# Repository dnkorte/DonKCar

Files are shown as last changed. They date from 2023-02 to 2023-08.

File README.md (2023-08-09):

This project holds files related to the DonKCar project, which is an
implementation of autonomous RC-sized racer.  The project includes
OpenSCAD code to generate 3d-printable chassis that fit a variety
of purchasable RC car platforms; the chassis is user-configurable
and currently includes built-in options to generate models including a 
variety of hardware configurations including Raspberry Pi
and/or Jetson Nano for DonkeyCar implementations, and OpenMV-based
solutions using ESP32-S2 on an Adafruit Metro board as a main controller.  

The OpenSCAD modules in this project are dependent on the use of the 
lib_robo files which are available in [a separate repository here](https://github.com/dnkorte/lib_robo).
The "include" links in the OpenSCAD modules must be updated
to point to the lib_robo library files, wherever you have stored them in
your filesystem

All plates may be automatically "split" so that they can be printed
on standard 180x180mm or larger 3d-printers.  The designs are currently 
configured for the following RC chassis:

*[1/10 Tamiya TT02B Neo Scorcher (2-post)](https://smile.amazon.com/gp/product/B00DSVF3BY)

*[1/10 Tamiya TT02 Toyota GR 86  (4-post)](https://www.amazon.com/TAMIYA-10-Toyota-TT-02-TAM58694/dp/B09KRR5GKS)

*[Hosim 1/12 Monster Truck](https://www.amazon.com/Hosim-9155-Speed-Monster-Trucks/dp/B07SRTHB3L?th=1) 

*[Holyton 1:10 Large High Speed Remote Control Car](https://www.amazon.com/dp/B08B1F3494)

*[Electric Infinitive EP RTR Off Road Truck](https://www.nitrorcx.com/51c803-truck-ttyellowcarbon.html)

Note that these are all readily available chassis in early 2023

<h3 align="center">
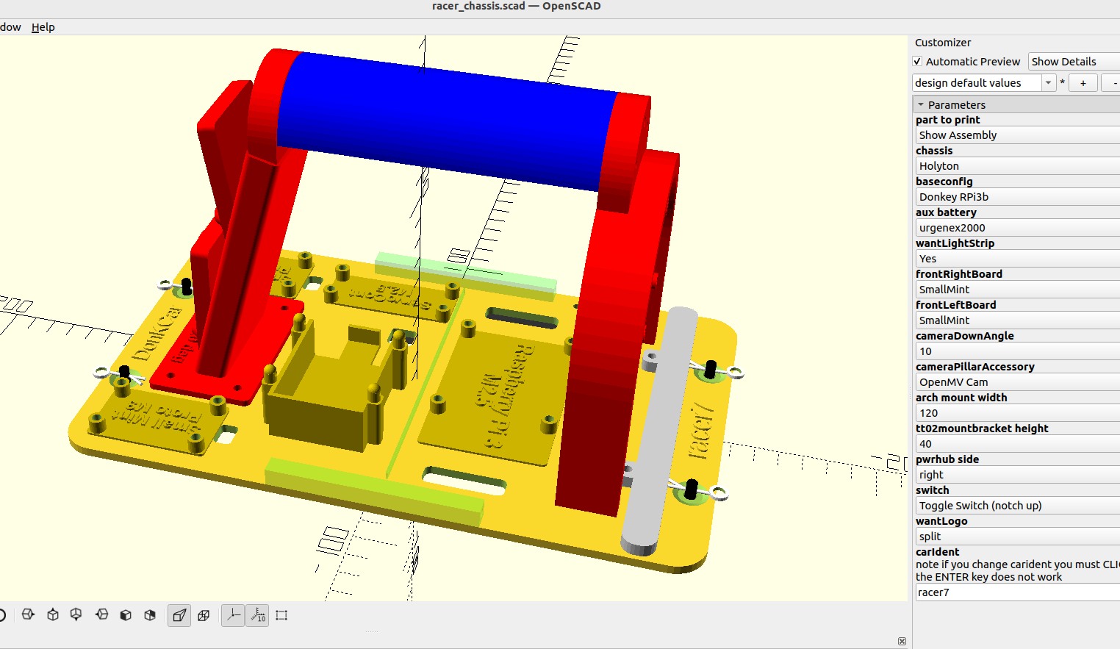
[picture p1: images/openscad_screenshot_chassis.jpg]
sample openscad screen
	<br>
</h3>

If using a standard DonkeyCar software package on either a Raspberry Pi or Jetson Nano, none of the Arduino code packages are needed, and the OpenSCAD models are very stable and complete for those configurations.

## ESP32-S2 + OpenMV Configuration

This project has includes an (optional) as-yet still under software/hardware development option  that uses an OpenMV camera for the vision and lane-tracking portions and uses an ESP32-S2 (Adafruit Metro ESP32-S2 board) as a vehicle / platform main controller.  At the current time, the manual driving and core functions are very complete and functional -- allowing manual driving of the vehicle using a remote controller (clips to driver's belt), and allowing for setup/configuration using a self-hosted web menu system that works with a phone or laptop (straight-up web interface no software installation needed on the phone or laptop).  The onboard ESP32-S2 software incorporates a 240x240 TFT display for detailed user feedback, and a 24 element NeoPixel strip that provides runtime feedback for users "at a distance" and also talks bi-directionally to the nunchuk controller.  

The belt-mounted remote controller uses an Adafruit Reverse Feather ESP32-S2 with a built-on TFT display connected to a Wii Nunchuk controller that provides driving commands. The remote communicates with the racer using ESP-NOW protocol which means that all control is totally independent of local networks, and is bi-directional and responsive.

All of the above works at the current time, with the software as included here.  

The autonomous driving functions using the OpenMV camera are still under development, but are modelled on the OpenMV line following protocols, modified to communicate to the main controller over an i2c connection.  The racer main controller handles the actual throttle and steering servo commands, accepting path commands provided by the OpenMV software.  

**Note that the ESP32-S2 / OpenMV configuration is currently very much still under development so use or reference at your own risk.**

<table><tr>
	<td>
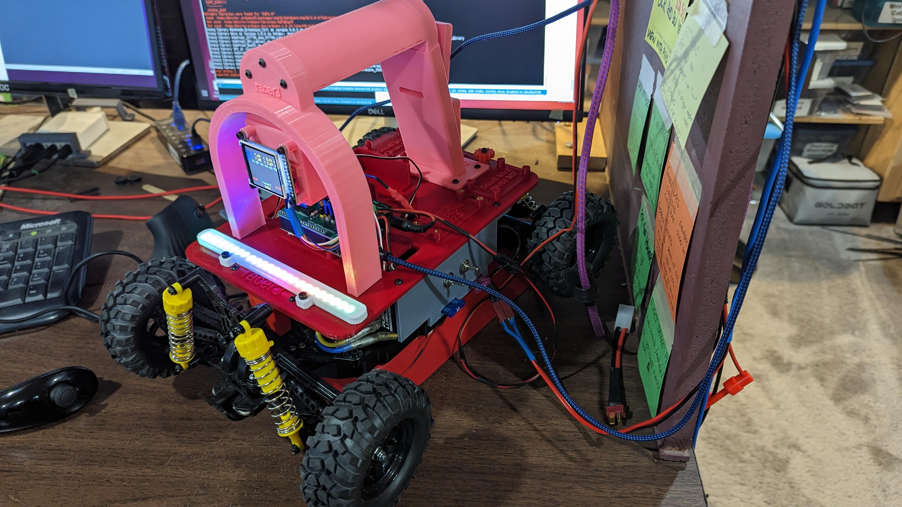
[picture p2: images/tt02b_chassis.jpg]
Tamiya TT02b 2-post chassis printed in 1 piece
		
	</td>
	<td>
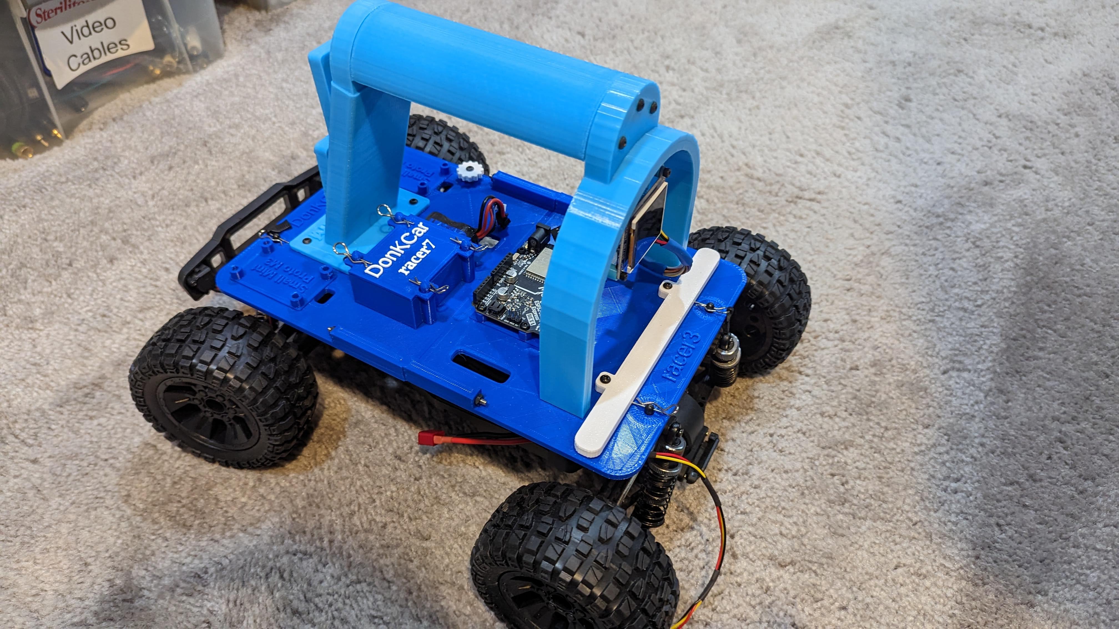
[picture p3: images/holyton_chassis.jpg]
Holyton RTR chassis printed in 2 pieces, joined
		
	</td>
	<td>
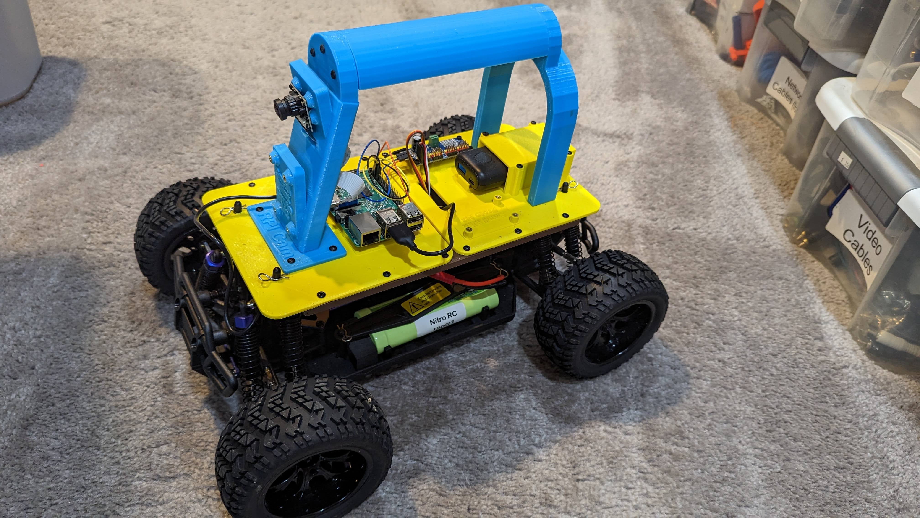
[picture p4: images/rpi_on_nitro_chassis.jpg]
Raspberry Pi on Nitro RCX chassis (older scad design)
		
	</td>
</tr></table>

## Remote Controller Using Nunchuk
The user controls the racer / robot using a Wii Nunchuk control unit that plugs into a belt-clipped or lanyard-mounted control box that includes a 240 x 135 TFT.  An [Adafruit Reverse TFT Feather](https://www.adafruit.com/product/5345) uses ESP-NOW protocol to communicate bi-directionally with the racer / robot.  It sends joystick and button-press commands to the racer, and receives messages back from racer for display on the TFT.  It is a very quick and responsive protocol with good range (at least 100 feet in my yard, but not tested any farther). The simple messaging protocol could be easily used to control any robot / racer configuration.  The control box is powered by a small LiPo battery and may be worn using a belt-clip or a [neck lanyard](https://www.amazon.com/Bestom-Breakaway-Lanyards-Lanyards-no-Twist/dp/B09LQJJHFQ) (of the type typically used for ID badges).  

Some photos of the controller box are shown below, or a more complete [photo album is available here](https://photos.app.goo.gl/xJtTXaHJivE7bsBp9), and [short video of unit in operation is linked here](https://photos.app.goo.gl/UN85hcr63vpKxPkb9).  Additionally, a document describing the communication protocol is available [here](https://github.com/dnkorte/DonKCar/blob/main/Protocol_for_Nunchuk_Controller_for_Racer_Robot.pdf)

<table><tr>
	<td>
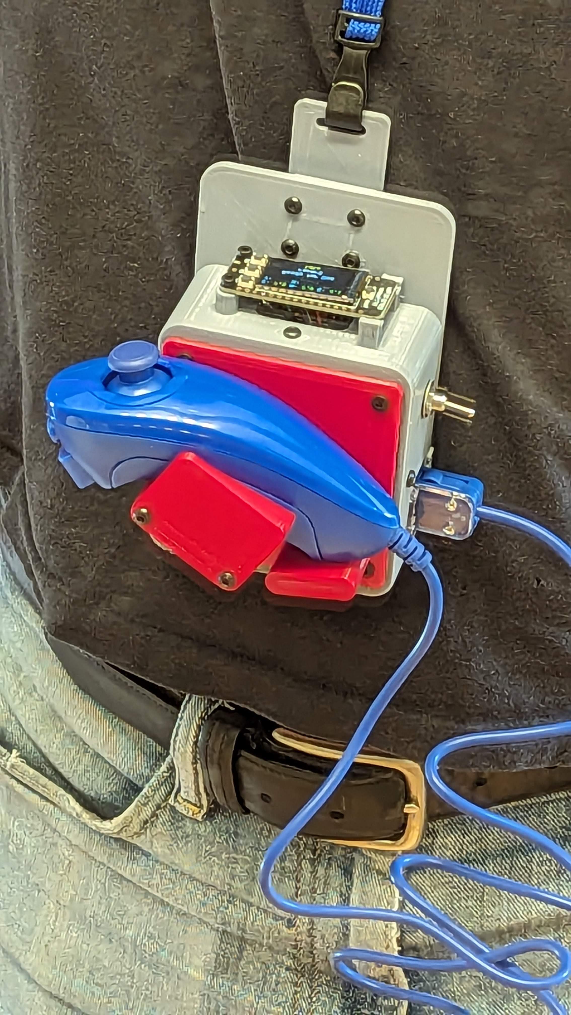
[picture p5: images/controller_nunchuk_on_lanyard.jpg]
Controller on Lanyard
		
	</td>
	<td>
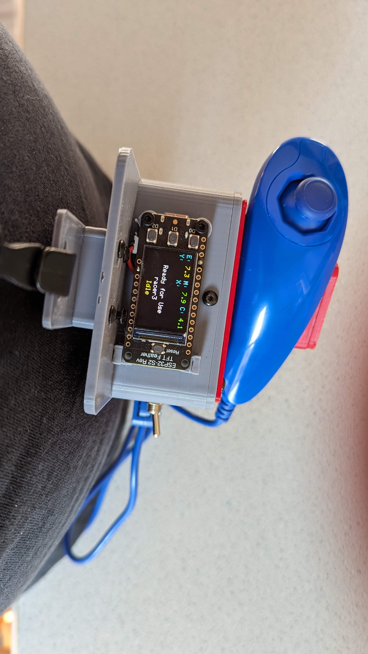
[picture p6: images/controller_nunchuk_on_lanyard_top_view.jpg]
Controller on Lanyard
		
	</td>
	<td>
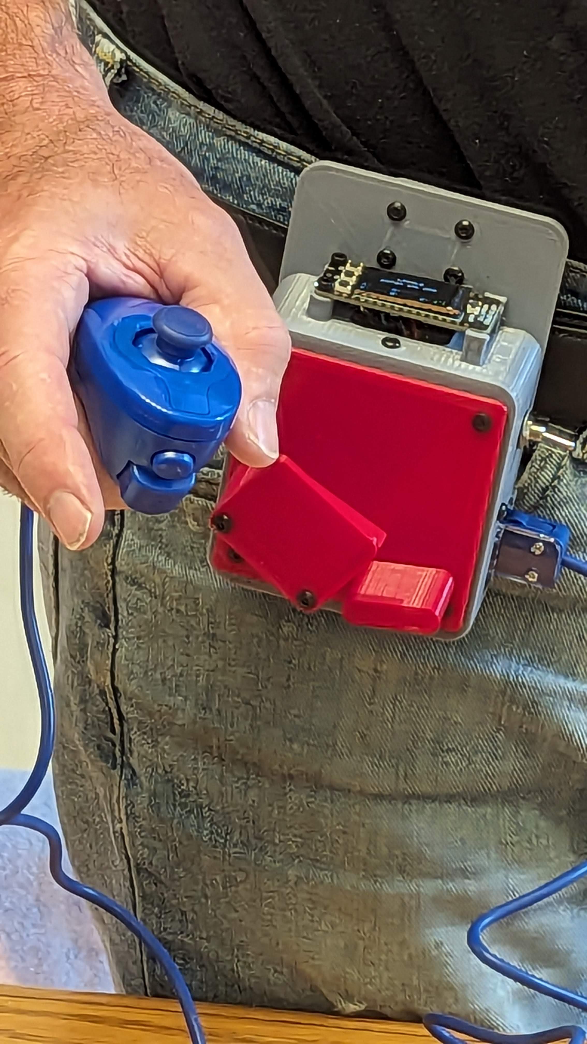
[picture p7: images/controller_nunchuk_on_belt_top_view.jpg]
Controller on belt-clip
		
	</td>
</tr><tr>
	<td colspan=3>
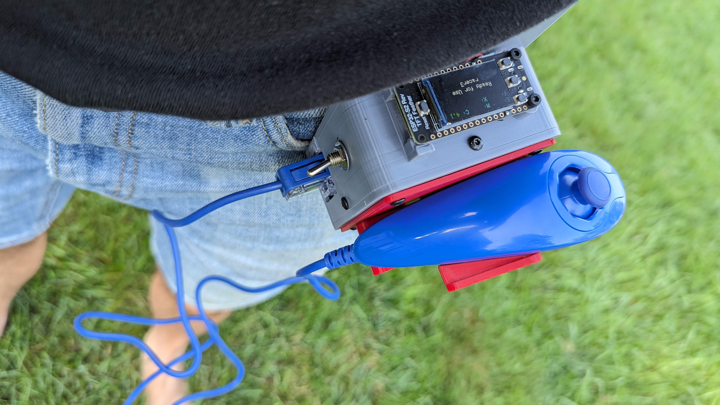
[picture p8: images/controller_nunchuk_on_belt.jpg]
Controller on belt-clip
		
	</td>

</tr></table>

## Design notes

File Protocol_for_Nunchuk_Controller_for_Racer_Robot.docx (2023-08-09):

# Protocol for Nunchuk Controller (racer/robot)

Messages between Controller and Robot are sent over ESP-NOW protocol, using short binary structures defined in the Arduino code as indicated in the following sections. The MAC address of the responding robot or racer is hard encoded into the “communic.cpp” module of the software. Note that in the current version of the software, there are 3 values indicated, though only the first one (index 0) is actually used at this time.

### Colorcodes

For those incoming messages that receive colorcodes, the code is a single char value, as follows:

- ‘G’ Green
- ‘Y’ Yellow
- ‘O’ Orange
- ‘R’ Red
- ‘W’ White
- ‘X’ Black
- ‘B’ Blue
- ‘C’ Cyan
- ‘P’ Purple
- ‘Z’ Medium Gray
- ‘H’ (header color; cyan)

### Controller to Robot Messages

typedef struct {

char msgtype; // 'C', 'Z', 'X', 'Y', 'V', 'H', '0', '1', '2'

int intdata; // note this is a 2-byte (16 bit) integer

} MessageCtoR; // this type (structure) holds a message that goes from

Controller to Robot

All messages are 3 bytes long, with the 1st byte indicating the message type, and the following 2 bytes (Arduino 2 byte integer) holding the value associated with the message. All reported intdata are LSB first.

Message type ‘C’ :

This indicates the status of the Nunchuk ‘C’ button (the “upper” one on the Nunchuk device). The intdata value is integer 1 when button PRESS is detected, and 0 when button RELEASE is detected.

Button 2

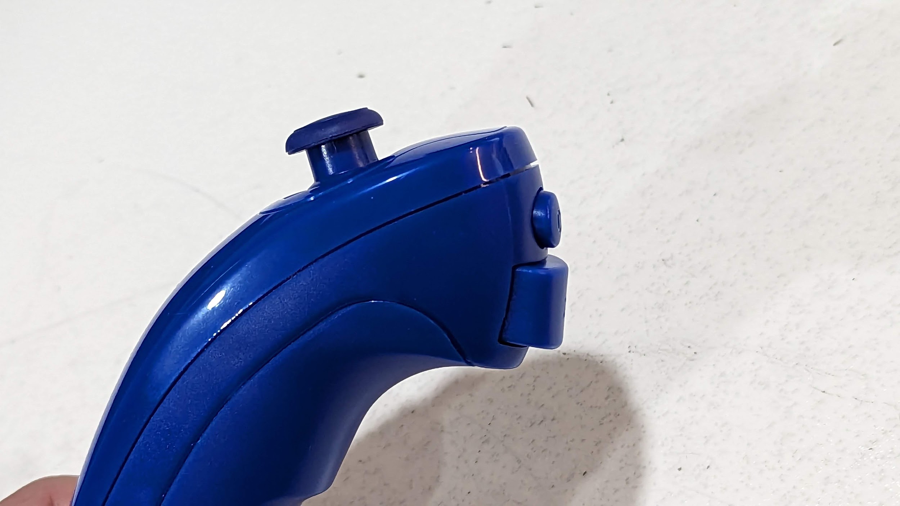
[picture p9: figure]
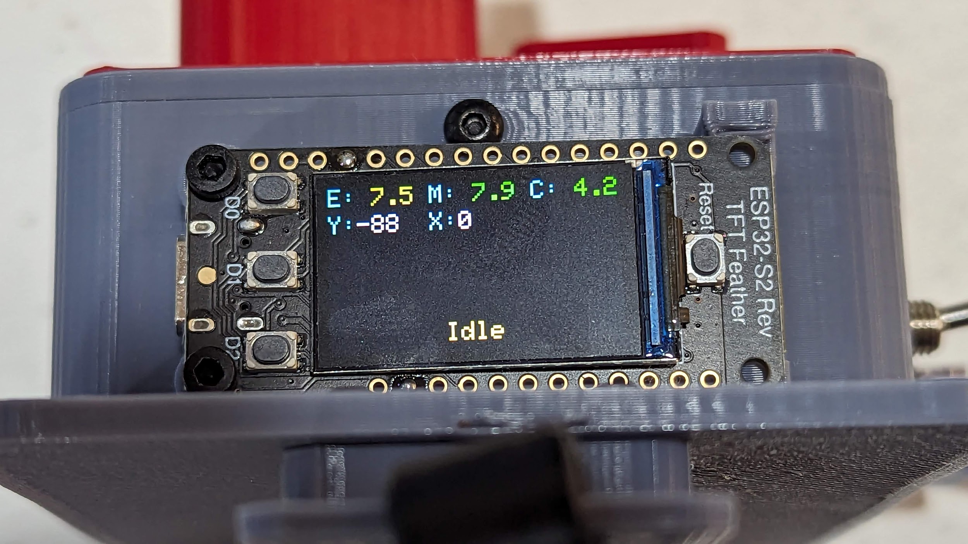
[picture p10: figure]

C button

Z button

Btn 0

Btn 1

Btn 2

Message type ‘Z’ :

This indicates the status of the Nunchuk ‘Z’ button (the “lower” one on the Nunchuk device). The intdata value is integer 1 when button PRESS is detected, and 0 when button RELEASE is detected.

Message type ‘0’ :

This indicates the status of the Feather ‘0’ button. The intdata value is integer 1 when button PRESS is detected, and 0 when button RELEASE is detected.

Message type ‘1’ :

This indicates the status of the Feather ‘1’ button. The intdata value is integer 1 when button PRESS is detected, and 0 when button RELEASE is detected.

Message type ‘2’ :

This indicates the status of the Feather ‘2’ button. The intdata value is integer 1 when button PRESS is detected, and 0 when button RELEASE is detected.

Message type ‘X’:

This message sends the X value of the joystick (left and right). The value in intdata is scaled such that FULL LEFT reports -255, and FULL RIGHT reports +255. The value is reported whenever it changes by 2 or more, and has a small deadband at center to reduce jitter.

Message type ‘Y’:

This message sends the Y value of the joystick (forward and back). The value in intdata is scaled such that FULL BACK reports -255, and FULL FORWARD reports +255. The value is reported whenever it changes by 2 or more, and has a small deadband at center to reduce jitter.

Message type ‘H’:

This message sends a “heartbeat’ indication to the racer / robot for the purpose of indicating that it is alive and connected. The message is sent once every 1000 mS. The intvalue is irrelevant in this message.

Message type ‘V’:

This message is currently not used, but is intended to send the binary value representing the battery voltage of the LiPo in the control box.

### Robot to Controller Messages - Battery Status

typedef struct {

uint8_t messagetype;

char colorcode;

float battvolts;

float cellvolts;

} MessageRtoC_batt; // this type (structure) holds a message that goes from

Robot to Controller

This message is sent from the racer / robot to the controller and indicates the robot’s battery voltage (and corresponding cell voltage for multi-cell batteries) for purposes of display.

- messagetype: 0 (MSG_VOLTS_E) indicates voltage of the PRIMARY battery (the one that feeds the processor and displays), 1 (MSG_VOLTS_M_ indicates the voltage of the MOTOR battery
- colorcode: character indicating color that should be used to display the passed voltages, per the table above. Generally the colorcode reflects the level of charge (ie, G/reen, Y/ellow, O/range, R/ed)
- battvolts: floating point value representing the battery voltage (ie 8.2). This is presented LSB first
- Cellvolts: floating point value representing the cell voltage (ie 3.7) for multicell batteries. Will be the same as battvolts for single cell batteries. This is presented LSB first

### Robot to Controller Messages - Status Text

typedef struct {

uint8_t messagetype;

char colorcode;

char text[22];

} MessageRtoC_text; // this type (structure) holds a message that goes from

Robot to Controller

This message type is sent from racer / robot to the controller and contains a text string for display on the controller’s TFT screen. There are 3 lines available for status messages. All messages are centered on their display line and are automatically cleared (erased) after 30 seconds.

- messagetype: 2 (MSG_STAT1) for first status line, 3 (MSG_STAT2) for second status line, 4 (MSG_STAT3) for third status line
- colorcode: character indicating color that should be used to display the passed text, per the table above.
- Text: the text to display as an Arduino character array; messages are null (\0) terminated

### Robot to Controller Messages - ModeMenu Text

typedef struct {

uint8_t messagetype;

char colorcode;

char text[22];

} MessageRtoC_text; // this type (structure) holds a message that goes from

Robot to Controller

This message type is sent from racer / robot to the controller and contains a text string for display on the bottom line of the controller’s TFT screen. The bottom line is typically used to indicate the “Mode” that the robot / racer is operating in, or about to operate in if is reflecting a menu possibility.

- messagetype: 5 (MSG_MENUITEM)
- colorcode: character indicating color that should be used to display the passed text, per the table above.
- Text: the text to display as an Arduino character array; messages are null (\0) terminated

### Robot to Controller Messages - Simple Message

typedef struct {

uint8_t messagetype;

char colorcode;

} MessageRtoC_simple; // this type (structure) holds a message that goes from

Robot to Controller

This message type is sent from racer / robot to the controller for simple commands or messages, such as “clear display” or “beep”. Currently neither of these messages are actually implemented for the controller

### Joystick Values Display

The second line of the controller’s TFT is used to display the joystick values, X and Y. This display is internally driven and does not require any messages from the robot / racer.

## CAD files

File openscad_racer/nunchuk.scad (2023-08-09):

/*
 * Module: nunchuk.scad
 * this main module generates a box to hold components of a belt-clip portable
 * box into which a user can plug a Wii Nunchuk controller which can then be
 * used to control an RC Car or robot. 
 *
 * Project: DonKCar
 * Author(s): Don Korte
 * github: https://github.com/dnkorte/DonKCar.git
 * 
 *  
 * MIT License
 * 
 * Copyright (c) 2023 Don Korte
 * 
 * Permission is hereby granted, free of charge, to any person obtaining a copy
 * of this software and associated documentation files (the "Software"), to deal
 * in the Software without restriction, including without limitation the rights
 * to use, copy, modify, merge, publish, distribute, sublicense, and/or sell
 * copies of the Software, and to permit persons to whom the Software is
 * furnished to do so, subject to the following conditions:
 * 
 * The above copyright notice and this permission notice shall be included in all
 * copies or substantial portions of the Software.
 * 
 * THE SOFTWARE IS PROVIDED "AS IS", WITHOUT WARRANTY OF ANY KIND, EXPRESS OR
 * IMPLIED, INCLUDING BUT NOT LIMITED TO THE WARRANTIES OF MERCHANTABILITY,
 * FITNESS FOR A PARTICULAR PURPOSE AND NONINFRINGEMENT. IN NO EVENT SHALL THE
 * AUTHORS OR COPYRIGHT HOLDERS BE LIABLE FOR ANY CLAIM, DAMAGES OR OTHER
 * LIABILITY, WHETHER IN AN ACTION OF CONTRACT, TORT OR OTHERWISE, ARISING FROM,
 * OUT OF OR IN CONNECTION WITH THE SOFTWARE OR THE USE OR OTHER DEALINGS IN THE
 * SOFTWARE.
 */

part_to_print="box with 1200 mAH";  // [ "box with 1200 mAH", "box with 500 mAH", "lid without hanger", "lid for Nunchuk cradle", "lid for Nunchuk hanger", "Nunchuk Cradle plate", "Cap for Nunchuk Cradle", "Nunchuk Hanger plate", "beltclip", "lanyard clip", "battbox_lid 500", "battbox_lid 1200", "test" ]

draw_part();

module draw_part() {
    $fn = 36;
    

    if (part_to_print == "beltclip") {
        part_beltclip();
    } else if (part_to_print == "lanyard clip") {
        part_lanyard_clip();
    } else if (part_to_print == "battbox_lid 500") {
        component_battbox_lipo_500_flat_lid();
    } else if (part_to_print == "battbox_lid 1200") {
        component_battbox_lipo_1200_flat_lid();
    } else if (part_to_print == "box with 1200 mAH") {
        box_feather("1200");
    } else if (part_to_print == "box with 500 mAH") {
        box_feather("500");
    } else if (part_to_print == "lid without hanger") {
        lid_feather("N");
    } else if (part_to_print == "lid for Nunchuk hanger") {
        lid_feather("H");
    } else if (part_to_print == "lid for Nunchuk cradle") {
        lid_feather("C");
    } else if (part_to_print == "Nunchuk Cradle plate") {
        nunchuk_cradle_plate();
    } else if (part_to_print == "Cap for Nunchuk Cradle") {
        nunchuk_cradle_cap();
    } else if (part_to_print == "Nunchuk Hanger plate") {
        nunchuk_hanger_plate();
    } else if (part_to_print == "test") {
        translate([ 0, 0, 2 ]) nunchuk_hanger();
        roundedbox(50, 50, 3, 2);
    }
}

box_length = 80;
box_width = 120;
box_height = 37;
box_corner_radius = 8;

feather_box_length = 80;
feather_box_width = 85;
feather_plate_width = 120;
feather_box_height = 35;
hanger_mount_sep = 42;
cradle_mount_sep = 62;

plate_thick = 3;
wall_thick = 5;
wall_height = 16;
corner_radius = 8;

plate_x = 80;
plate_y = 120;

beltclip_hole_sep_x = 20;
beltclip_hole_sep_y = 15;

mountplate_thick = 2;

/*
 ************************************************************************************************
 * this includes all of the needed library modules
 ************************************************************************************************
 */
include <../../lib_robo/config_core.scad>;
include <../../lib_robo/config_box.scad>
include <../../lib_robo/components_core.scad>;
include <../../lib_robo/components_boards.scad>;
include <../../lib_robo/components_switches_and_lights.scad>;
include <../../lib_robo/components_power_batteries.scad>;
include <../../lib_robo/components_power_boards.scad>;
include <../../lib_robo/components_power_fuses_connectors.scad>;
//include <../../lib_robo/components_camera_rollbar.scad>;
include <../../lib_robo/simple_box_and_lid.scad>
include <../../lib_robo/components_robo_misc.scad>; 

/*
 * *****************************************************************
 * mainl box-building code for drawing parts
 * most standard components are already handled here, by means
 * of configuration parameters, however custom parts may be
 * added by adding appropriate code to these modules
 * *****************************************************************
 */

module box_feather(batteryFlavor = "1200") {
    nunchuk_window_wide = 27;   // was 27
    nunchuk_window_tall = 20;   // should raise it 5 above box bottom (was 22)

    usb_window_wide = 14;
    usb_window_tall = 8;
    usb_window_height = 15;

    difference() {
        union() {
            // the basic hollow box
            difference() {
                roundedbox(feather_box_length, feather_box_width, box_corner_radius, box_height);
                translate([0, 0, body_bottom_thickness])  
                    roundedbox((feather_box_length - 2*body_wall_thickness), 
                           (feather_box_width - 2*body_wall_thickness), 
                           box_corner_inner_radius, 
                           (box_height - body_wall_thickness+1));
            }

            /*
             ************************************************************************
             * here enter all the parts that are added to the box
             ************************************************************************
             */
            translate([  0, -(feather_plate_width-feather_box_width)/2, 0 ]) roundedbox( box_length, feather_plate_width, box_corner_radius, plate_thick);

            if (batteryFlavor == "1200") {
                translate([ -10, 5, plate_thick ]) rotate([ 0, 0, 0 ]) component_battbox_lipo_1200_flat("adds");
            } else {
                translate([ -10, 0, plate_thick ]) rotate([ 0, 0, 0 ]) component_battbox_lipo_500_flat("adds");
            }

            translate([ (plate_x/2)-13, 20, plate_thick-1 ]) rotate([ 0, 0, 90 ]) part_nunchuk();
            
            translate([ (plate_x/2)-1, 20, 1 ]) rotate([ 90, 90, 90 ]) rotate([ 0, 0, 90 ]) 
                linear_extrude(2) text("Notch", size=6,  halign="center", font = "Liberation Sans:style=Bold");  

            translate([ 0, -(feather_box_length/2)-1.5, plate_thick+15 ]) rotate([ 90, 180, 0 ]) component_reverse_feather(mode="adds", mount_height=7);

        }

        // create mounting holes along y side (by removal...)
        translate([-(box_length/2)-0.1, 0, (box_height - mount_center_offset_from_boxtop)]) rotate([0,90,0])  
              cylinder(h=box_length+0.2, r=screwhole_radius_M30_passthru);
      
        // create mounting holes along x side
        translate([0, -(box_width/2)-0.1, (box_height - mount_center_offset_from_boxtop)]) rotate([0,90,90])  
              cylinder(h=box_width+0.2, r=screwhole_radius_M30_passthru);

        /*
         ************************************************************************
         * here enter all the parts that are removed from the box
         ************************************************************************
         */
        translate([ 0, -63, -0.1 ]) component_beltclip_mount();


        if (batteryFlavor == "1200") {
            translate([ -10, 5, plate_thick ]) rotate([ 0, 0, 0 ]) component_battbox_lipo_1200_flat("holes");
        } else {
            translate([ -10, 0, plate_thick ]) rotate([ 0, 0, 0 ]) component_battbox_lipo_500_flat("holes");
        }

        translate([ (box_length/2)+0.1, -20, box_height/2 ]) rotate([ 90, 180, 0 ]) rotate([ 0, 90, 180 ]) component_mini_toggle_switch("holes");

        translate([ 0, -(feather_box_length/2)+0, plate_thick+15 ]) rotate([ 90, 0, 0 ]) roundedbox( 30, 16, 3, 6);
        translate([ 0, -(feather_box_length/2)-1.5, plate_thick+15 ]) rotate([ 90, 180, 0 ]) component_reverse_feather(mode="holes", mount_height=7);

        // access hole for nunchuk connector
        translate([ (plate_x/2)+0.1, 20, 4.2 + plate_thick + (nunchuk_window_tall/2) ]) rotate([ 0, -90, 0 ]) 
            roundedbox( nunchuk_window_tall, nunchuk_window_wide, 2, body_wall_thickness+0.2); 

    }
}


module lid_feather(want_plate = "C") {   
    difference() {

        union() {
            roundedbox(feather_box_length, feather_box_width, box_corner_radius, lid_thickness);
            translate([0, 0, lid_thickness]) lip(feather_box_length, feather_box_width);
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

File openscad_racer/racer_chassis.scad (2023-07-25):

/*
 * Module: racer_chassis.scad
 * this main module generates 3d-printable mounting plates and 
 * components for a variety of purchasable RC Car chassis platforms. 
 * these chassis hold cameras and electronics to support Autonomous Racer
 * projects.  Use of the OpenSCAD "customizer" allows the user to simply
 * select appropriate parts to build various configurations of racer --
 * including built-in options compatible with DonkeyCar Raspberry Pi 3b,
 * DonkeyCar Jetson Nano, and a custom DonKCar platform based on the OpenMV
 * camera running in conjunction with ESP32 based communication and main control.
 *
 * Project: DonKCar
 * Author(s): Don Korte
 * github: https://github.com/dnkorte/DonKCar.git
 * 
 *  
 * MIT License
 * 
 * Copyright (c) 2023 Don Korte
 * 
 * Permission is hereby granted, free of charge, to any person obtaining a copy
 * of this software and associated documentation files (the "Software"), to deal
 * in the Software without restriction, including without limitation the rights
 * to use, copy, modify, merge, publish, distribute, sublicense, and/or sell
 * copies of the Software, and to permit persons to whom the Software is
 * furnished to do so, subject to the following conditions:
 * 
 * The above copyright notice and this permission notice shall be included in all
 * copies or substantial portions of the Software.
 * 
 * THE SOFTWARE IS PROVIDED "AS IS", WITHOUT WARRANTY OF ANY KIND, EXPRESS OR
 * IMPLIED, INCLUDING BUT NOT LIMITED TO THE WARRANTIES OF MERCHANTABILITY,
 * FITNESS FOR A PARTICULAR PURPOSE AND NONINFRINGEMENT. IN NO EVENT SHALL THE
 * AUTHORS OR COPYRIGHT HOLDERS BE LIABLE FOR ANY CLAIM, DAMAGES OR OTHER
 * LIABILITY, WHETHER IN AN ACTION OF CONTRACT, TORT OR OTHERWISE, ARISING FROM,
 * OUT OF OR IN CONNECTION WITH THE SOFTWARE OR THE USE OR OTHER DEALINGS IN THE
 * SOFTWARE.
 */

part_to_print="Show Assembly";  // [ "Top Plate", "Top Plate (front half)", "Top Plate (back half)", "Show Assembly", "RPi Cam Pillar (no handle)", "RPi Cam Pillar (with handle)", "OpenMV Cam Pillar (no handle)", "OpenMV Cam Pillar (with handle)", "Back Arch", "Back Arch w/TFT", "NeoPixel Bezel Indoors", "NeoPixel Bezel Outdoors", "Handle", "Mount Pillar (car-to-plate; TT02 single-post design)", "Power Hub", "Fuse Holder Lid", "Battery Box Lid", "Thumbnut 12", "Thumbnut 15", "Thumbnut 18", "Thumbnut 18 tall", "Thumbnut 18 super",  "test" ]

chassis = 0; // [0:TT02B-2, 1:TT02B-2 Extended, 2:TT02-4, 3:Holyton, 4:Hosim, 5:Exceed, 6:Custom ]

baseconfig = "metro"; // ["metro", "Donkey RPi3b", "Donkey Jetson Nano"]
aux_battery = "none"; // ["none", "anker6700", "urgenex2000", "NiMH 7.2v 2200 mAH" ]

wantLightStrip = "Yes"; // [ "Yes", "No" ]

frontRightBoard = "None"; // ["SmallMint", "None"]
frontLeftBoard = "None"; // ["SmallMint",  "None"]

cameraDownAngle = 10;	// [ 5, 10, 12, 15, 17, 20, 25, 30, 35 ]
cameraPillarAccessory = "OpenMV Cam"; // [ "OpenMV Cam", "RPi Cam", "SmallMint Proto", "None"]
arch_mount_width = 120; // [ 88, 120, 135 ]

tt02mountbracket_height = 40; // [ 35, 40, 45, 50 ]

pwrhub_side = "right"; // ["right", "left"]
switch = "Toggle Switch (notch up)"; // [ "Toggle Switch (notch up)", "Toggle Switch (notch down)", "Boat Rocker Switch"]

wantPCA9685 = "only Pi/Nano"; // ["only Pi/Nano", "all configurations"]

wantLogo = "split"; // [ "arch", "split", "none" ]
// note if you change carident you must CLICK out of box; the ENTER key does not work
carIdent = "racer3";


/*
 *********************************************************************
 * define a dummy function here, to stop the configurator "fields phase"
 *********************************************************************
 */

module dummy() {
	// this doesn't do anything useful
}

/*
 *********************************************************************
 * define other parameters that don't want configurator fields
 *********************************************************************
 */

// note for all dimensions on plate, the center of the body mount pins is the origin (0,0) point
// and "forward" is (+), "backward" is (-);  left is (-), right is (+)

// note indices are:  0/TT02-2,      1/TT02-2 ext, 2/TT02-4,   3/Holyton,   4/Hosim,   5/Exceed,  6/Custom

pillars_fb_sep =      [ 224,         224,         260,         253,         194,       261,			253 ];
// left/right separation may be different at front end than at back, so here show [front sep, back sep]
pillars_lr_sep =      [ [60,60],     [60,60],     [65,65],     [73,83],     [54,54],    [80,80],	    [73,83] ];
pillars_dia = 		  [ 3.5,         3.5,		  7.2,         5.5,         5.5,        7.2, 		7.2 ];
pillars_max_depth =	  [ 4,           4,           4,           3,           1.8,          4,          4 ];

added_fronts =        [ 10,          10,          10,          10,          65,         10,			10 ];
added_backs =         [ 10,          30,          10,          10,          10,         10, 		10 ];
plate_widths =        [ 170,         170,         170,         170,         170,        170, 		170 ];

// ligthstrip locations (POSITIVE but as distance behind origin), 2nd parameter is "n" or "r"
// "n" indicates normal mounting-tab-forward orientation, "r" indicates mounting-tab-backward orientation
lightStrip_locs =     [ [101,"r"],    [130,"n"],   [108,"r"],  [110,"n"],   [78,"r"],   [112,"n"], 	[110,"n"] ];

// for these features, params are x, y
metro_locs =          [ [0,-42],     [0,-50],     [0,-40],     [0,-38],     [0,-22],    [0,-44],    [0,-38] ];
rpi3b_locs =          [ [0,-42],     [0,-50],     [0,-40],     [0,-39],     [0,-22],    [0,-44],    [0,-38] ];
jetson_locs =         [ [0,-52],     [0,-55],     [0,-46],     [0,-47],     [0,-28],    [0,-48],    [0,-47] ];
frontL_locs = 		  [ [-58, 92],   [-58, 92],   [-60, 100],  [-60, 100],  [-60, 124],  [-62, 100], [-60, 101] ];
frontR_locs =         [ [58, 92],    [58, 92],    [60, 100],   [60, 100],   [60, 124],   [62, 100],  [60, 101] ];

// for servo locs, params are x, y, z-rotation
servo_locs =          [ [58, 23],    [58, 21],    [58, 31],    [58, 28],    [58, 50],   [58, 32],   [58, 28] ];

// for aux batteries, params are x, y, z-rotation
auxb_ank67_info =     [ [35,47,180], [35,47,180], [35,52,180], [35,54,180], [35,76,180], [35,60,180],  [35,54,180]  ];
auxb_urge_info =      [ [-55,2,0],   [-55,2,0],   [-55,12,0],  [-55,9,0],   [-55,32,0],   [-55,12,0],  [-55,9,0]  ];
auxb_nimh2200_info  = [ [-64,-4,0],  [-64,-6,0],  [-64,4,0],   [-64,3,0],   [-64,25,0],   [-64,5,0],   [-64,3,0]  ];

// note wirehole_locs indicate right-side hole, but there is also a left-side hole that mirrors is
wirehole_locs =       [ [60,-38],    [60,-42],    [60,-36],    [60,-36],    [60,-12],   [60,-42],   [60,-36] ];

// location where top plate is split for 3d printing convenience
// 0 means exact middle of plate, + is number of mm FORWARD of middle, - is mm BEHIND middle
split_locs = 		  [ -10,        -13,         -3,          -5,          16,         -4,  	   -5 ];
joiner_centers = 	  [ 0,          -0,           3,           2,          8,           4, 		    2 ];

// for camera / arch info, paramters are (y location of camera plate center), (length of handle)
// note that the arch center is towards the back of the chassis, which is why the y location is (negative)
cam_to_arch_info = 	  [ [82, 107],  [80, 126],    [90, 125],  [90, 127],   [138, 140], [93, 132],   [90, 127] ];

cam_to_arch_separation = cam_to_arch_info[ chassis][1];
cam_arch_loc_y = cam_to_arch_info[ chassis][0];

camera_center_y = cam_to_arch_info[chassis][0];
handle_length = cam_to_arch_info[chassis][1];
arch_center_y = camera_center_y - handle_length - 50;

pwrhub_mount_sep = 120;
pwrhub_mount_inset = 8;

plate_y = pillars_fb_sep[chassis] + added_fronts[chassis] + added_backs[chassis];
plate_x = plate_widths[chassis];	
plate_thick = 4;
corner_radius = 14;
					
front_edge = (plate_y/2);
back_edge = -(plate_y/2);
left_edge = -(plate_x/2);
right_edge = (plate_x/2);

/*
 ************************************************************************************************
 * this includes all of the needed library modules
 ************************************************************************************************
 */
include <../../lib_robo/config_core.scad>;
include <../../lib_robo/components_core.scad>;
include <../../lib_robo/components_boards.scad>;
include <../../lib_robo/components_switches_and_lights.scad>;
include <../../lib_robo/components_power_batteries.scad>;
include <../../lib_robo/components_power_boards.scad>;
include <../../lib_robo/components_power_fuses_connectors.scad>;
include <../../lib_robo/components_camera_rollbar.scad>;
include <../../lib_robo/components_robo_misc.scad>; 

draw_part();

module draw_part() {
    $fn = 24;
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

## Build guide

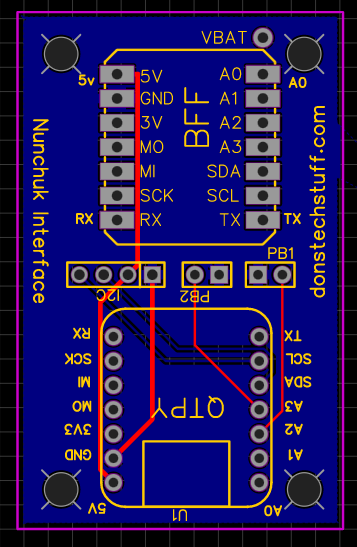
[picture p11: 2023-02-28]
hardware_printed_circuit_boards/board_nunchuk.png

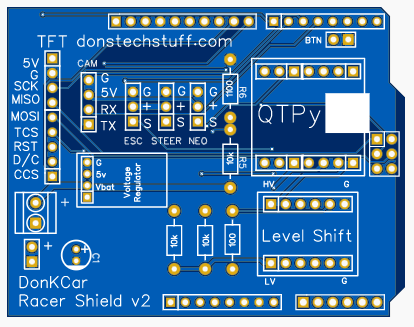
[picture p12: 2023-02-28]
hardware_printed_circuit_boards/board_racer3.png

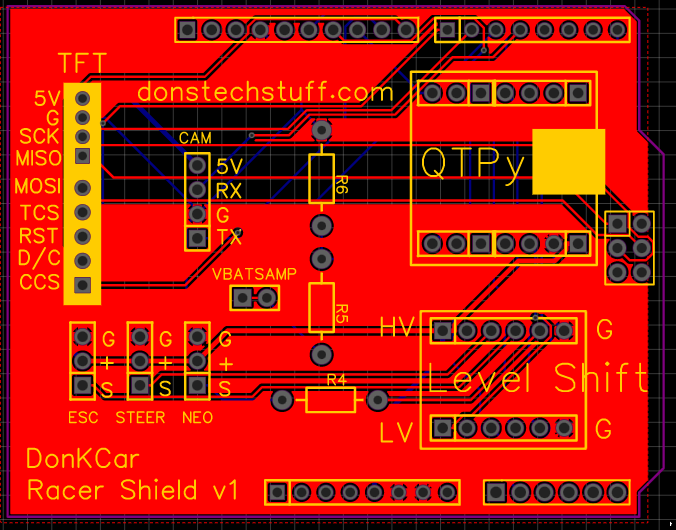
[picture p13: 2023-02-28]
hardware_printed_circuit_boards/screenshot_board_top.png

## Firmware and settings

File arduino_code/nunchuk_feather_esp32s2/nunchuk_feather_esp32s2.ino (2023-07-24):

/*
 * Summary: remote controller for robots/racers uses nunchuk as actuator
 *    communicates to robot/racer using ESP-NOW protocol; this version
 *    runs on an Adafruit QTPy ESP32-S2 and has an oled display
 * 
 * Author(s):  Don Korte
 * Repository: https://github.com/dnkorte/DonKCar
 *
 * MIT License
 * Copyright (c) 2023 Don Korte
 * 
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
 * **********************************************************************************
 * **********************************************************************************
 * this project utilizes the Nintendo Extension Controller Library by David Madison
 *  @link       github.com/dmadison/NintendoExtensionCtrl
 *  @license    LGPLv3 - Copyright (c) 2018 David Madison
 *  https://github.com/dmadison/NintendoExtensionCtrl  
 *  
 *  Note this works with either the literal Woo "Nunchuk" device or the Wii Classic Controller
 *  Nunchuk Controller: https://www.amazon.com/Nunchuck-Controller-Joystick-Gamepad-Console/dp/B07RLBN9Z2
 *  Nunchuk COntroller: https://www.amazon.com/Nunchuck-Controller-Joystick-Gamepad-Console/dp/B083TRZZK7/
 *  Classic Controller: https://www.amazon.com/JYELUK-Classic-Controller-Compatible-White/dp/B0BZV1RR6Z
 *  Classic Controller: https://www.amazon.com/Zettaguard-Controller-classic-Console-Gampad-Nintendo/dp/B00XH1FV3
 *  Connector Breakout: https://www.adafruit.com/product/4836
 *
 * **********************************************************************************
 * **********************************************************************************            
*/

#include "config.h"

#include <NintendoExtensionCtrl.h>
#include "communic.h"
#include "screen_tft.h"
#include "status.h"
#include "battery.h"
#include <Wire.h>

#define HEARTBEAT_INTERVAL 1000

String jsonBuffer;
int lastJoyY, lastJoyX;
bool lastButtonC, lastButtonZ;
int button_state, lastButton_0_State, lastButton_1_State, lastButton_2_State;
bool nunchukConnected;
long current_time;
long lastHeartbeatMsg;  
long nextBattDispDue;
long nextHeartbeat;
long nextStatusMessageClearCheck;

Nunchuk nchuk;

/*
 * private function declarations
 */

/* 
 * Setup
 */

void setup() {

  status_neopixels_init();

  /*
   * note we're goint to flash the on-board neopixel a few times
   * here to give progress indication of startup.  but there's really
   * a dual purpose -- it takes OLED and/or Nunchuk board a little while
   * to wake up after powerup, and the delays in these display functions
   * give them time to do that.  if left out, then substitute a delay 
   * early in startup routine to give equivalent time
   */
  status_neopixel_flash(0xFFFFFF);

  // note it takes a while for Serial to start; this empty loop waits for it
  // ref   https://forum.arduino.cc/t/cant-view-serial-print-from-setup/167916
  #ifdef DEBUG
    Serial.begin(115200); 
    while (!Serial) ;
  #endif

  status_init(); 
  screen_centerText(ROW_M_STAT2, "Screen Initialized", ST77XX_BLUE);
  screen_show();  
  status_neopixel_flash(0x0000FF);  // BLUE indicates past screen
  
	nchuk.begin();
  nunchukConnected = false;
	while (!nchuk.connect()) {
    // try to reconnect, but due to lack of i2c hot-plugging capability
    // it will probably need a physical reboot
    status_neopixel_flash(0xc41a00);  // ORANGE indicates error nunchuk
    screen_centerText(ROW_M_STAT1, "Please Plug in", ST77XX_RED);
    screen_centerText(ROW_M_STAT2, "the Nunchuk device", ST77XX_RED);
    screen_centerText(ROW_M_STAT3, "then reboot", ST77XX_RED);
    screen_show();
		delay(1000);
	} 
  nunchukConnected = true;
	status_clear_status_area();   
  screen_centerText(ROW_M_STAT2, "Nunchuk Initialized", ST77XX_GREEN);
  screen_show();
  status_neopixel_flash(0x00FF00);  // GREEN indicates past nunchuk

  lastJoyY = 0;
  lastJoyX = 0;
  lastButtonC = false;
  lastButtonZ = false;
  lastButton_0_State = 1;
  lastButton_1_State = 1;
  lastButton_2_State = 1;
    
  communic_init();  
  screen_centerText(ROW_M_STAT2, "Radio Initialized", ST77XX_YELLOW);
  screen_show(); 
  status_neopixel_flash(0xFFFF00);  // YELLLOW indicates past communic

  pinMode(PIN_BUTTON_0, INPUT_PULLUP);
  pinMode(PIN_BUTTON_1, INPUT_PULLUP);
  pinMode(PIN_BUTTON_2, INPUT_PULLUP);
  
  nextHeartbeat = millis() + HEARTBEAT_INTERVAL;
  nextBattDispDue = millis() + 20;
  nextStatusMessageClearCheck = millis() + 263;
  
  batt_init();
  status_main_structure();    
  screen_centerText(ROW_M_STAT2, "Ready for Use", ST77XX_WHITE);
  screen_centerString(ROW_M_STAT3, communic_connected_device(), ST77XX_WHITE);
  screen_show(); 
}

void loop() {
  int rawJoyX, rawJoyY, centeredJoyX, centeredJoyY, scaledJoyX, scaledJoyY;
	boolean success;
  char tmpBuf[12];

  current_time = millis();
  success = nchuk.update();  // Get new data from the controller
  
	if (!success) {  // Ruh roh
    // try to reconnect, but due to lack of i2c hot-plugging capability
    // it will probably need a physical reboot
    screen_centerText(ROW_M_STAT1, "Please Plug in", ST77XX_RED);
    screen_centerText(ROW_M_STAT2, "the Nunchuk device", ST77XX_RED);
    screen_centerText(ROW_M_STAT3, "then reboot", ST77XX_RED);
    screen_show();    
    nunchukConnected = false;
		delay(1000);
    nchuk.connect();
	}
	else {
    if (!nunchukConnected) {      
      nunchukConnected = true;
      status_clear_status_area();
    }
    
		// Read a button (on/off, C and Z)
		boolean zButton = nchuk.buttonZ();
    boolean cButton = nchuk.buttonC();
    rawJoyX = nchuk.joyX();
    rawJoyY = nchuk.joyY();

    centeredJoyX = rawJoyX;
    centeredJoyY = rawJoyY;

    // then centralize both joysticks to zero center
    centeredJoyX = centeredJoyX - JOY_CENTER;
    centeredJoyY = centeredJoyY - JOY_CENTER;

    // finally scale joystick values to represent -255 to +255
    scaledJoyX = map(centeredJoyX, JOY_X_MIN - JOY_CENTER, JOY_X_MAX - JOY_CENTER, -255, 255);
    scaledJoyY = map(centeredJoyY, JOY_Y_MIN - JOY_CENTER, JOY_Y_MAX - JOY_CENTER, -255, 255);

    if (scaledJoyX > 255) {
      scaledJoyX = 255;
    }
    if (scaledJoyX < -255) {
      scaledJoyX = -255;
    }
    
    if (scaledJoyY > 255) {
      scaledJoyY = 255;
    }
    if (scaledJoyY < -255) {
      scaledJoyY = -255;
    }
    
    // make a deadband around CENTER for both joysticks
    if ((scaledJoyX < (JOY_DEADBAND)) && (scaledJoyX > (-JOY_DEADBAND))) {
      scaledJoyX = 0;
    }
    if ((scaledJoyY < (JOY_DEADBAND)) && (scaledJoyY > (-JOY_DEADBAND))) {
      scaledJoyY = 0;
    }
    
    if (zButton != lastButtonZ) {
      if (zButton) {
        communic_send_message('Z', 1);
        //screen_writeText_colrow(COL_M_NUN_BTNS_LAB+0, ROW_M_NUNCHUK_INFO, 1, "Z", COLOR_GREEN);
      } else {
        //communic_send_message("zbutn=0");  
        communic_send_message('Z', 0);
        //screen_writeText_colrow(COL_M_NUN_BTNS_LAB+0, ROW_M_NUNCHUK_INFO, 1, " ", COLOR_FOREGROUND);      
      }
      //screen_show();
    }
   
    if (cButton != lastButtonC) {
      if (cButton) {
        communic_send_message('C', 1);
        //screen_writeText_colrow(COL_M_NUN_BTNS_LAB+1, ROW_M_NUNCHUK_INFO, 1, "C", COLOR_RED);
      } else {
        //communic_send_message("cbutn=0");
        communic_send_message('C', 0);
        //screen_writeText_colrow(COL_M_NUN_BTNS_LAB+1, ROW_M_NUNCHUK_INFO, 1, " ", COLOR_FOREGROUND);        
      }
      //screen_show();
    }
   
    if (abs(scaledJoyX - lastJoyX) > 1) { 
      communic_send_message('X', scaledJoyX);
      screen_writeText_colrow(COL_M_NUN_X_LAB+2, ROW_M_NUNCHUK_INFO, 4, itoa(scaledJoyX, tmpBuf, 10), COLOR_FOREGROUND);
      screen_show();
    }
   
    if (abs(scaledJoyY - lastJoyY) > 1) {; 
      communic_send_message('Y', scaledJoyY);
      screen_writeText_colrow(COL_M_NUN_Y_LAB+2, ROW_M_NUNCHUK_INFO, 4, itoa(scaledJoyY, tmpBuf, 10), COLOR_FOREGROUND);
      screen_show();
    }
     
    lastJoyY = scaledJoyY;
    lastJoyX = scaledJoyX;
    lastButtonC = cButton;
    lastButtonZ = zButton;
	}
 
  button_state = digitalRead(PIN_BUTTON_0);
  if (button_state != lastButton_0_State) {
    if (button_state == 0) {  // pressed      
      //screen_writeText_colrow(COL_M_NUN_BTNS_LAB+2, ROW_M_NUNCHUK_INFO, 1, "0", COLOR_ORANGE);;
      //screen_show();
    } else {    
      //screen_writeText_colrow(COL_M_NUN_BTNS_LAB+2, ROW_M_NUNCHUK_INFO, 1, " ", COLOR_FOREGROUND);
      //screen_show();
    }
    lastButton_0_State = button_state;
  }
 
  button_state = digitalRead(PIN_BUTTON_1);
  if (button_state != lastButton_1_State) {
    if (button_state == 0) {  // pressed      
      //screen_writeText_colrow(COL_M_NUN_BTNS_LAB+3, ROW_M_NUNCHUK_INFO, 1, "1", COLOR_ORANGE);;
      //screen_show();
    } else {    
      //screen_writeText_colrow(COL_M_NUN_BTNS_LAB+3, ROW_M_NUNCHUK_INFO, 1, " ", COLOR_FOREGROUND);
      //screen_show();
    }
    lastButton_1_State = button_state;
  }
 
  button_state = digitalRead(PIN_BUTTON_2);
  if (button_state != lastButton_2_State) {
    if (button_state == 0) {  // pressed      
      //screen_writeText_colrow(COL_M_NUN_BTNS_LAB+4, ROW_M_NUNCHUK_INFO, 1, "2", COLOR_ORANGE);;
      //screen_show();
    } else {    
      //screen_writeText_colrow(COL_M_NUN_BTNS_LAB+4, ROW_M_NUNCHUK_INFO, 1, " ", COLOR_FOREGROUND);
      //screen_show();
    }
    lastButton_2_State = button_state;
  }

  
  if (current_time > nextHeartbeat) {
    communic_send_message('H', 1);
    nextHeartbeat = millis() + HEARTBEAT_INTERVAL;
  }
  
  if (current_time > nextBattDispDue) {
    nextBattDispDue = current_time + 60000;
    display_my_mybatt();
  }
  
  if (batt_has_new_data_ready('E')) {
    display_remote_mybatts();
  }
  if (batt_has_new_data_ready('M')) {
    display_remote_mybatts();
  }

  // display any new status messages or menu lines that came in over espnow
  status_display_mainscreen_messages();
  

  /* 
   *  implement "clear status message" process after appropriate timeouts
   *  (note messages time out after 30 seconds)
   */
  if (current_time > nextStatusMessageClearCheck) {
    nextStatusMessageClearCheck = current_time + 100;
    status_message_area_clear_check();   // check for menu timeouts
  }

  delay(50);
}

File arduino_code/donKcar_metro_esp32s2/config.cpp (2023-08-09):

/*
 * Summary: openMV + esp32 based autonomous racer
 * 
 * Author(s):  Don Korte
 * Repository: https://github.com/dnkorte/DonKCar
 *
 * MIT License
 * Copyright (c) 2020 Don Korte
 * 
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
 * THE SOFTWARE IS PROVIDED "AS IS", WITHOUT WARRANTY OF ANY KIND, EXPRESS OR
 * IMPLIED, INCLUDING BUT NOT LIMITED TO THE WARRANTIES OF MERCHANTABILITY,
 * FITNESS FOR A PARTICULAR PURPOSE AND NONINFRINGEMENT. IN NO EVENT SHALL THE
 * AUTHORS OR COPYRIGHT HOLDERS BE LIABLE FOR ANY CLAIM, DAMAGES OR OTHER
 * LIABILITY, WHETHER IN AN ACTION OF CONTRACT, TORT OR OTHERWISE, ARISING FROM,
 * OUT OF OR IN CONNECTION WITH THE SOFTWARE OR THE USE OR OTHER DEALINGS IN THE
 * SOFTWARE. * 
/*
 * ******************************************************************************
 * ******************************************************************************
 * this module gets and manages robot configuration parameters
 * the config.h file has default values for all user-configurable parameters
 * but cfg_init() attempts to read an SD card to get "actual" values for
 * these parameters.   It is based significantly on the following modules
 *    https://arduinojson.org/v6/example/config/
 *    https://arduinojson.org/?utm_source=meta&utm_medium=library.properties
 * it assumes that an attached SD card has a file called "/config.txt"
 * which is a json file with the specified values
 * ******************************************************************************
 * ******************************************************************************
 */
#include <Arduino.h>
#include <SPI.h>
#include <SdFat.h>                // SD card & FAT filesystem library (adafruit version)
#include <Adafruit_SPIFlash.h>    // SPI / QSPI flash library (adafruit version)
#include <ArduinoJson.h>
#include "config.h"
#include "util.h"
#include "status.h"

 /*
 * ******************************************************************************
 * ******************************************************************************
 * DEFAULT VALUES for user-configurable parameters
 * generally these do not need to be changed as they are
 * suitable generic values for getting the racer up and running
 *
 * when changes are made to a specific racer's configuration
 * they should be done using the web-based configuration utility
 * or by directly editing the json configuration on the SD card (/config.txt) 
 * ******************************************************************************
 * ******************************************************************************
 */

#define ROBOT_NAME "myracer"    // note this should be limited to 8 characters

#define STEER_CENTER_US  1440   // was 1440
#define STEER_LEFT_US    1100   // was 1020
#define STEER_RIGHT_US   1750   // was 1750

#define STEERING_FRACTION 0.12    // (note could set this to 0.35 if using superslow MAX_THROT 160)

#define MANUAL_SPEED_CREEP 64     // driving speed during manual creep (-255 to +255) 
#define MANUAL_SPEED_NORMAL 128   // normal driving throttle (-255 to +255)
#define MANUAL_SPEED_BOOST 128   // normal driving throttle (-255 to +255)
#define MANUAL_SPEED_TURNS  64    // throttle on turns
#define MANUAL_TURN_THRESHOLD 32  // steering PWM above which MANUAL_SPEED_TURNS is triggered
#define AUTO_SPEED_NORMAL 128     // normal driving throggle
#define AUTO_SPEED_TURNS 64       // throttle on turns
#define THROT_START_PWM 32        // pwm for start pulse when starting from stopped condition
#define THROT_START_DURATION 2    // duration of start pulse in 10 mS increments
#define ACCEL_LIMIT 20          

#define ESC_ARM_SIGNAL 1000       // uS to write during arming period
#define ESC_ARM_TIME 3000         // mS long for arming
#define ESC_MIN_THROTTLE 1070
#define ESC_MAX_THROTTLE 1852
#define ESC_REVERSE_THROTTLE 1502 // orig 1488

#define BATT_E_SCALE 7.212      // this times raw a/d raw reading = mV
#define BATT_E_NUMCELLS 2       // typically 3 (11.1v 3S) or 2 (7.4v 2S)
#define BATT_E_USED true        // true = this battery is used, false = not used
#define BATT_E_MIN_GREEN  3.75   // cell voltages above this will be displayed in green
#define BATT_E_MIN_YELLOW 3.5
#define BATT_E_MIN_ORANGE 3.28   // below this value will be displayed in red and cause shutdown
#define BATT_E_SHUTDOWN_ON_RED true  // shutdown racer if battery goes red

#define BATT_M_SCALE 7.212      // this times raw a/d raw reading = mV
#define BATT_M_NUMCELLS 2       // typically 3 (11.1v 3S) or 2 (7.4v 2S)
#define BATT_M_USED false        // true = this battery is used, false = not used
#define BATT_M_MIN_GREEN  3.75   // cell voltages above this will be displayed in green
#define BATT_M_MIN_YELLOW 3.5
#define BATT_M_MIN_ORANGE 3.28   // below this value will be displayed in red and cause shutdown
#define BATT_M_SHUTDOWN_ON_RED false  // shutdown racer if battery goes red
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

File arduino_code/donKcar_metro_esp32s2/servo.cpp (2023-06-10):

/*
 * Summary: openMV + esp32 based autonomous racer
 * 
 * Author(s):  Don Korte
 * Repository: https://github.com/dnkorte/DonKCar
 *
 * MIT License
 * Copyright (c) 2020 Don Korte
 * 
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
 * THE SOFTWARE IS PROVIDED "AS IS", WITHOUT WARRANTY OF ANY KIND, EXPRESS OR
 * IMPLIED, INCLUDING BUT NOT LIMITED TO THE WARRANTIES OF MERCHANTABILITY,
 * FITNESS FOR A PARTICULAR PURPOSE AND NONINFRINGEMENT. IN NO EVENT SHALL THE
 * AUTHORS OR COPYRIGHT HOLDERS BE LIABLE FOR ANY CLAIM, DAMAGES OR OTHER
 * LIABILITY, WHETHER IN AN ACTION OF CONTRACT, TORT OR OTHERWISE, ARISING FROM,
 * OUT OF OR IN CONNECTION WITH THE SOFTWARE OR THE USE OR OTHER DEALINGS IN THE
 * SOFTWARE. * 
 */
#include "servo.h"

/*
 * *************************************************************************************
 * NOTE: functions from this module should only be called from the following modules
 * drivetrain.cpp (for normal driving), webap_api.cpp (for configuration)
 * because (drivetrain.cpp wraps these in functions that also update the TFT display
 * *************************************************************************************
 */

/*
 *****************************************************************************************************************************
  DNK NOTE: demo for servo use on ESP32S2 -- note that must use library ESP32_S2_IS_Servo by Khoi Hoang
  for ESP32-S2 devices (ie QTPY ESP32S2), rather than ESP32_Servo (which is ok for WROOM32 devices)
  DNK NOTE: note the library accepts arguments of 0 to 180 (no negative, no 270))
 
  ESP32_S2_MultipleServos.ino
  For ESP32_S2 boards
  Written by Khoi Hoang
  
  Built by Khoi Hoang https://github.com/khoih-prog/ESP32_ISR_Servo
           https://www.arduino.cc/reference/en/libraries/esp32_s2_isr_servo/
  Licensed under MIT license
  
  The ESP32 has two timer groups, each one with two general purpose hardware timers. All the timers
  are based on 64 bits counters and 16 bit prescalers
  The timer counters can be configured to count up or down and support automatic reload and software reload
  They can also generate alarms when they reach a specific value, defined by the software.
  The value of the counter can be read by the software program.
  
  Now these new 16 ISR-based PWM servo contro uses only 1 hardware timer.
  The accuracy is nearly perfect compared to software timers. The most important feature is they're ISR-based timers
  Therefore, their executions are not blocked by bad-behaving functions / tasks.
  This important feature is absolutely necessary for mission-critical tasks.
  
  Notes:
  Special design is necessary to share data between interrupt code and the rest of your program.
  Variables usually need to be "volatile" types. Volatile tells the compiler to avoid optimizations that assume
  variable can not spontaneously change. Because your function may change variables while your program is using them,
  the compiler needs this hint. But volatile alone is often not enough.
  When accessing shared variables, usually interrupts must be disabled. Even with volatile,
  if the interrupt changes a multi-byte variable between a sequence of instructions, it can be read incorrectly.
  If your data is multiple variables, such as an array and a count, usually interrupts need to be disabled
  or the entire sequence of your code which accesses the data.


  for PCA9685 use Adafruit PCS9685 module
  https://www.adafruit.com/product/815
  https://learn.adafruit.com/16-channel-pwm-servo-driver
  
 ****************************************************************************************************************************
*/

int servoSteering, servoThrottle;

/*
 * ************************************************************************
 * ************************************************************************
 * ************************************************************************
 * ***** if using Native ESP32-S2 timer functions *************************
 * ************************************************************************
 * ************************************************************************
 * ************************************************************************
 */
 
#ifdef SERVO_NATIVE_ESP32S2
  #include "ESP32_S2_ISR_Servo.h"
  
  // Select different ESP32 timer number (0-3) to avoid conflict
  #define USE_ESP32_TIMER_NO          3   // orig 3
  
  #define TIMER_INTERRUPT_DEBUG       0
  #define ISR_SERVO_DEBUG             0
  
  /*
   * ************************************************************************
   * private functions  SERVO_NATIVE_ESP32S2
   * ************************************************************************
   */ 
  
  /*
   * sets pulse width; note that a 50 Hz update rate is assumed (20 mS)
   *  @param pulseWidth is duration in microseconds
   */
  void set_pulsewidth(int servoIndex, uint16_t pulseWidth) {
    uint16_t myPosition;
  
    myPosition = pulseWidth;
    ESP32_ISR_Servos.setPulseWidth(servoIndex, myPosition);
  }
  
  /*
   * ************************************************************************
   * public functions  SERVO_NATIVE_ESP32S2
   * ************************************************************************
   */ 
  void servo_init(void) {
    int temp;
    
    //Select ESP32 timer USE_ESP32_TIMER_NO
    ESP32_ISR_Servos.useTimer(USE_ESP32_TIMER_NO);  
    servoSteering = ESP32_ISR_Servos.setupServo(PIN_SERVO_STEER, SERVO_MIN_MICROS, SERVO_MAX_MICROS);
    servoThrottle = ESP32_ISR_Servos.setupServo(PIN_SERVO_THROT, SERVO_MIN_MICROS, SERVO_MAX_MICROS); 
    servo_disable_servos();
  }
  
   void servo_enable_servos() {
    ESP32_ISR_Servos.enable(servoSteering);
    ESP32_ISR_Servos.enable(servoThrottle);
   }
   
   void servo_disable_servos() {
    ESP32_ISR_Servos.disable(servoSteering);
    ESP32_ISR_Servos.disable(servoThrottle);
   }
#endif  // SERVO_NATIVE_ESP32S2

/*
 * ************************************************************************
 * ************************************************************************
 * ************************************************************************
 * ***** if using PCA9685 16-channel PWM board ****************************
 * ************************************************************************
 * ************************************************************************
 * ************************************************************************
 */

/*
 * ************************************************************************
 * private functions  SERVO_PCA9685
 * ************************************************************************
 */
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

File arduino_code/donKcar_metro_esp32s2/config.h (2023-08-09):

/*
 * Summary: openMV + esp32 based autonomous racer
 * 
 * Author(s):  Don Korte
 * Repository: https://github.com/dnkorte/DonKCar
 *
 * MIT License
 * Copyright (c) 2020 Don Korte
 * 
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
 * *****************************************************************
 * OpenMV Autonomous Racers  configuration     
 * *****************************************************************
 */

#ifndef CONFIG_H
#define CONFIG_H

/*
 * *****************************************************************
 * macro to support debugging
 * *****************************************************************
 */


#ifdef DEBUG
  #define DEBUG_PRINTLN(x)  Serial.println(x)
  #define DEBUG_PRINT(x)  Serial.print(x)
#else
  #define DEBUG_PRINTLN(x)
  #define DEBUG_PRINT(x)
#endif

/*
 * ***************************************************
 * public functions for config
 * ***************************************************
 */

void cfg_init(void); 
void cfg_save(void);
String cfg_showfile();

/*
 * ***************************************************
 * public data for config
 * ***************************************************
 */

struct Config {
  char robot_name[10];  
  float batt_E_scale;
  int batt_E_numcells;
  bool batt_E_used;
  bool batt_E_shutdown_on_red;
  float batt_E_min_green;
  float batt_E_min_yellow;
  float batt_E_min_orange;   
  float batt_M_scale;
  int batt_M_numcells;
  bool batt_M_used;
  bool batt_M_shutdown_on_red;
  float batt_M_min_green;
  float batt_M_min_yellow;
  float batt_M_min_orange;   
  int steer_center_us;
  int steer_left_us;
  int steer_right_us;
  float steering_fraction;
  int manual_speed_creep;     
  int manual_speed_normal;  
  int manual_speed_boost;
  int manual_speed_turns;
  int manual_turn_threshold;
  int auto_speed_normal;
  int auto_speed_turns;
  int throt_start_pwm;
  int throt_start_duration;
  int accel_limit;
  
  int esc_arm_signal;
  int esc_arm_time;
  int esc_min_throttle;
  int esc_max_throttle;
  int esc_reverse_throttle;  

  int cam_startup_mode;   // (by index 0/Blob, 1/1-Line (regression), 2/Lane Lines
  int blob_roiTloc;
  int blob_roiTheight;
  int blob_roiMloc;
  int blob_roiMheight;
  int blob_roiBloc;
  int blob_roiBheight;
  float blob_roiTweight;
  float blob_roiMweight;
  float blob_roiBweight;
  float blob_float_thresh;
  float blob_seed_thresh;
  int blob_seed_loc;
  float pid_kp;
  float pid_ki;
  float pid_kd;

  int blob_lumi_low;
  int blob_lumi_high;
  int cam_histeq_wanted;  // 0/no, 1/yes
  int cam_negate_wanted;  // 0/no, 1/yes
  
  int pid_steering_direction; // DEPRECATE (by index 0 means NORMAL, 1 means reverse
  float pid_steering_gain;    // DEPRECATE
  float cam_perspective_factor; // DEPRECATE typ 0.1 - 1.0
  int cam_perspective_wanted;   // DEPRECATE (by index 0 means NO, 1 means YES
    
  int readconfirm;
};

//struct Globals {
//  bool batt_show_raw;
//};

extern Config config;  
//extern Globals globals; 

/*
 * ************************************************************************
 * Fundamental Switch for 2-wheel differential drive vs RS PWM drive
 * (note that all RC flavor systems are build on METRO ESP32-S2 platform
 * ************************************************************************
 */

#define FLAVOR_RC
//#define FLAVOR_DIFFERENTIAL

/*
 * *******************************************************************
 * ******************************************************************* 
 * ******************************************************************* 
 * Hardware PINS and "board usage" configuration
 * the items below are compiled-in constants that are "static" 
 * in the sense that they define hardware pins that are not 
 * typically changed "on the fly" so do not need to be in the user
 * changeable configuration flash
 * *******************************************************************
 * ******************************************************************* 
 * *******************************************************************
 */
 
/*
 * *******************************************************************
 * ******************************************************************* 
 *   RC Chassis configuration - using PWM signals for throt & steer
 * ******************************************************************* 
 * *******************************************************************
 */
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

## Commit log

2023-03-01 fixed batt box lid pegs/pins specification
    [racer_chassis.scad]
2023-03-01 increased height of plate joiner to facilitate easier wrenching
    [mainboard.fzz, racer_chassis.scad]
2023-03-08 added servoconverter option to power hub
    [racer_chassis.scad]
2023-03-09 updated nunchuk box nunchuk window and added USB access window; also added supertall thumbnut
    [nunchuk.scad, racer_chassis.scad]
2023-05-10 shortened length of power hub to provide more clearance for front tires steering
    [nunchuk.scad, racer_chassis.scad]
2023-05-10 made PCA9685 optionally available for non donkey builds
    [racer_chassis.scad]
2023-05-10 added arduino code to repo
2023-05-11 moved arduino code to cleaner folders
2023-05-15 added box for feather version of nunchuk controller
    [nunchuk.scad, racer_chassis.scad]
2023-05-15 added 1200 mAH LiPo for nunchuk
    [nunchuk.scad, racer_chassis.scad]
2023-05-19 setup nunchuk to select battery size
    [nunchuk.scad]
2023-05-19 flipped toggle switch notch up, moved belt clip to provide more clearance for TFT
    [nunchuk.scad]
2023-05-23 built reverse tft feather version of nunchuk remote
    [battery.cpp, config.h, nunchuk_feather_esp32s2.ino]
2023-05-24 added screen message to indicate nunchuk connection failure
    [nunchuk_feather_esp32s2.ino]
2023-06-10 added support for PCA9685 servo driver
2023-07-24 added (very preliminary) camera support for driving
    [nunchuk.scad, racer_chassis.scad]
2023-07-25 added Indoor/Outdoor option to neopixel bezel
    [racer_chassis.scad]
2023-08-09 added lanyard mount to nunchuk controller; also some in-process updates to camera controller
    [nunchuk.scad]
2023-08-31 modified so ESPNOW remote can select target robot by button 0 press
